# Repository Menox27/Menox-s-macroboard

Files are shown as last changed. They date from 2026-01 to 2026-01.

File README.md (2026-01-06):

# Menox-s-macroboard

This is my personal Macroboard controlled by a XIAO R2040. I redid it multiple times and this is the final version I am quite proud of. thanks to @Simon who helped me alot and thanks to whom I was able to improve my skills drasticly.
It got 9 keys, each with RGB-LEDs, a rotary encoder and a 0.91 OLED. This macroboard will be used to improve my workflow and just add more features to my setup.<br>

{3137F356-2468-4DAC-AE8C-1B506F517E0D}<br>

Schematic: <br>
This is the schematic. I split all the seperate components into diffrent wiring groups:<br>

{0275A107-F9AF-41F4-A477-3A9B39075D7F}

PCB:<br>
This is how I connected everything. It´s a little bit messy but I tried to keep it as straight forward as possible, only used 4 vias in the whole projekt and added a little bit of spongebob art.
In case you are wondering about the setup: The XIAO is mounted on the back so the OLED can be placed right above it on the frontside<br>

{1DEBE477-7064-4DE1-A112-2E3BDAD45E22}

Case:<br>
This is the case I came up with. It has a layer to mount the switches and one to hide the OLEDs parts that I dont want to be seen.<br>
{F8A3C546-25B9-4F1C-808D-FF561A60D7B6}

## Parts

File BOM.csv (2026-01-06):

Quantity | Part | Cost | Note
1x | PCB | 2€ (included) | Mainbody
1x | XIAO RP2040 | 5.50€ (included) | Microcontroller
9x | MX-Style Switches | 5.85€ (included) | Mechanical Switches
9x | any Keycaps | Filament | 3D printed
9x | Through-Hole-Diodes | 1.10€ (included) | Signal diodes
9x | SK6812 MINI-E LEDs | 0.27€ (included) | RGB Lighting
1x | EC11 Rotary Encoder | 0.65€ (included) | Input
1x | 0.91 inch OLED | 1.65€ (included) | Display
12x | M3 heatset inserts | 0.66€ (included) | Case hardware
4x | M3 Screws | 0.08€ (included) | Case hardware
1x | Macroboard-Case | Filament | 3D printed

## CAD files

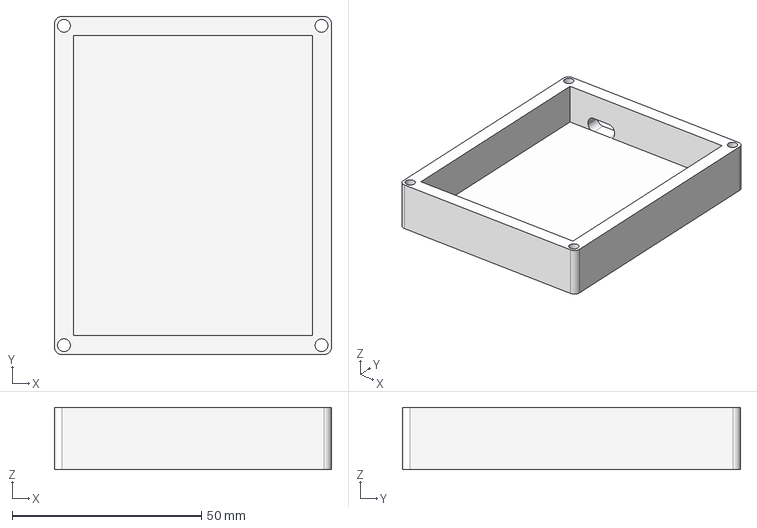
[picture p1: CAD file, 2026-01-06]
CAD/MacroboardBottomLayer.step
73.2 x 89.4 x 16.5 mm

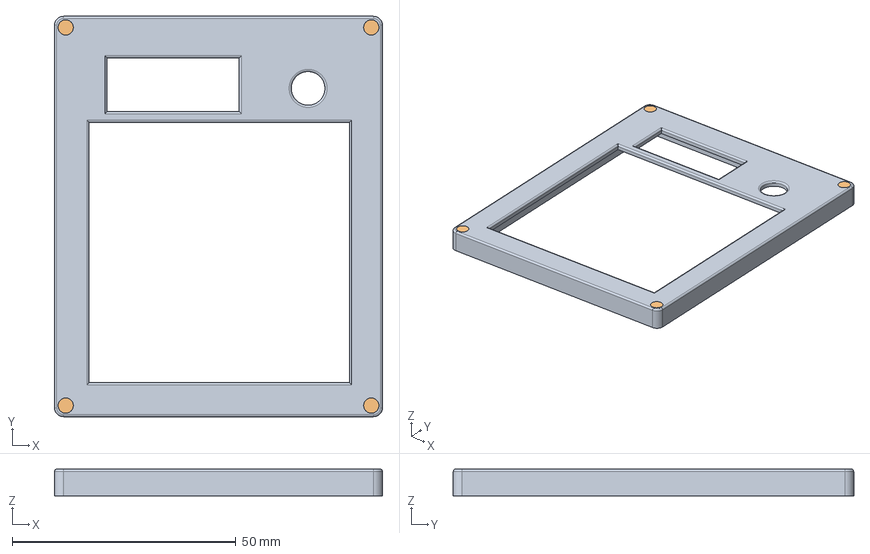
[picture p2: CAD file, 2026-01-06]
CAD/MacroboardTopLayer.step
73.2 x 89.4 x 6.00 mm

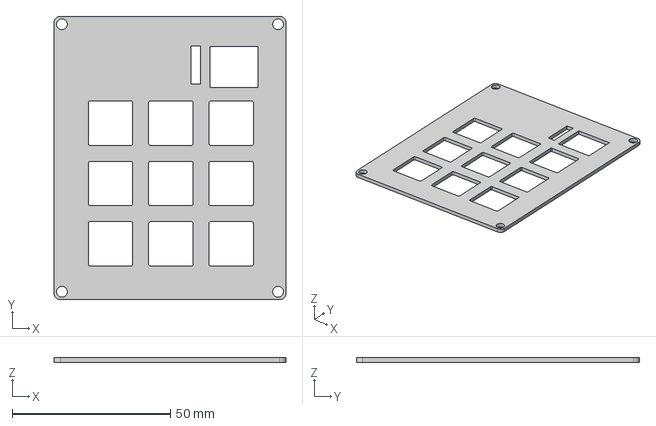
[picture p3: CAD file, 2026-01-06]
CAD/MacroboardMiddleLayer.step
73.2 x 89.4 x 1.50 mm

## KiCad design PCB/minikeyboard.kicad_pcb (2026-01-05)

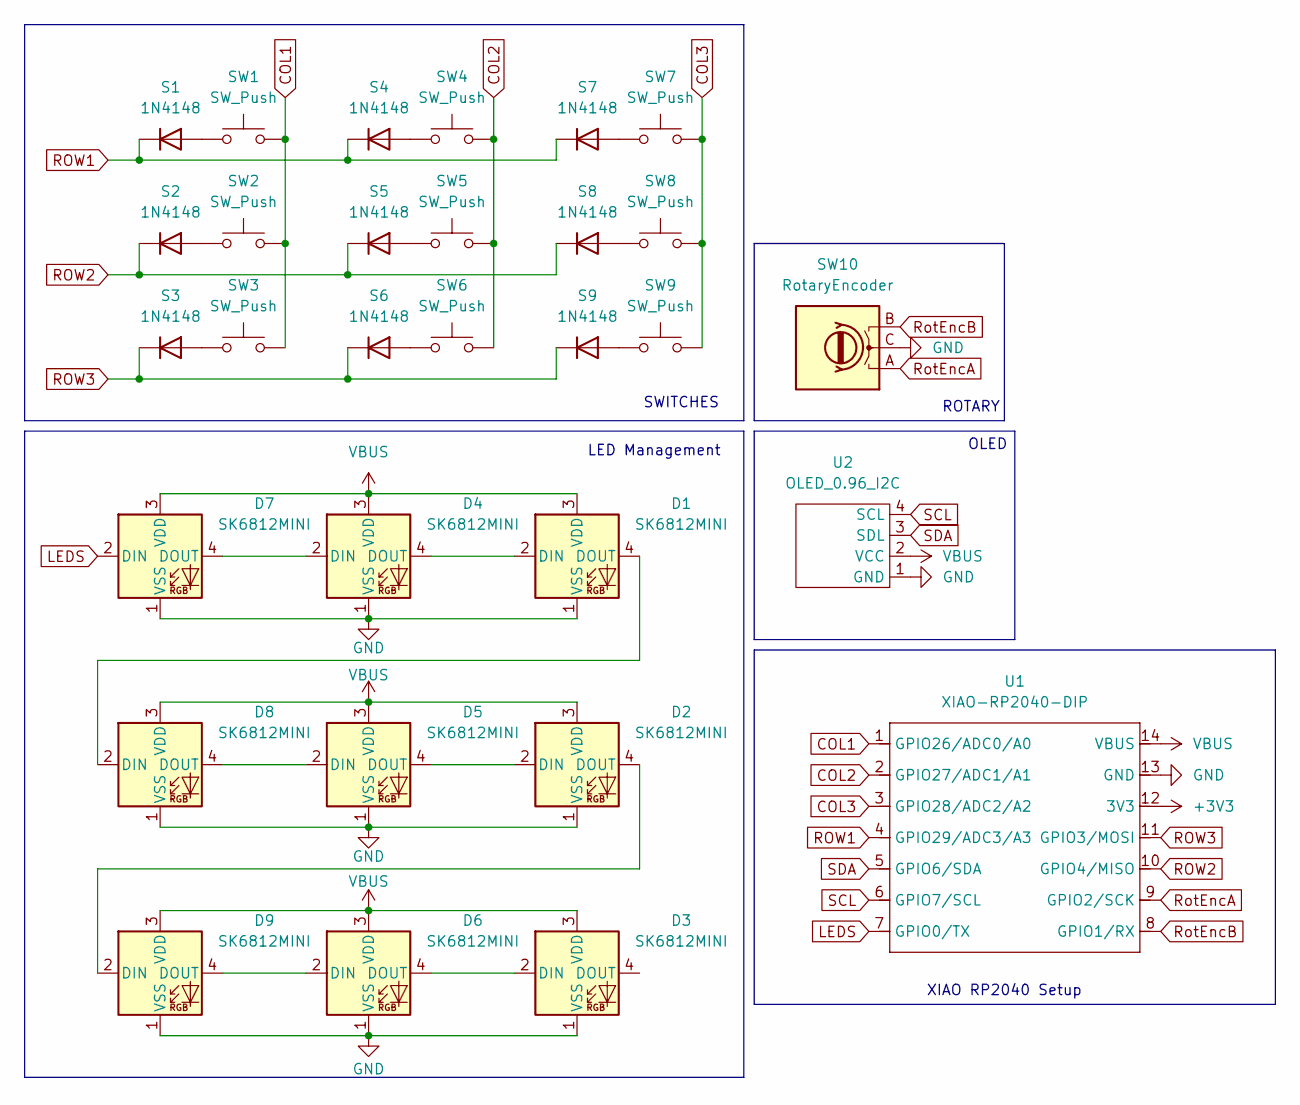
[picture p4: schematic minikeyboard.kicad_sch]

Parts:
D1, D2, D3, D4, D5, D6, D7, D8, D9: SK6812MINI; LED_SK6812MINI-E_PLCC4_3.2x2.8mm_P1.5mm
S1, S2, S3, S4, S5, S6, S7, S8, S9: 1N4148; D_DO-35_SOD27_P7.62mm_Horizontal
SW1, SW2, SW3, SW4, SW5, SW6, SW7, SW8, SW9: SW_Push; SW_Cherry_MX_1.00u_PCB
SW10: RotaryEncoder; RotaryEncoder_Alps_EC11E_Vertical_H20mm
U1: XIAO-RP2040-DIP
U2: OLED_0.96_I2C; SSD1306-0.91-OLED-4pin-128x32

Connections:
+3V3: U1.12 (3V3)
COL1: SW1.2, SW2.2, SW3.2, U1.1 (GPIO26/ADC0/A0)
COL2: SW4.2, SW5.2, SW6.2, U1.2 (GPIO27/ADC1/A1)
COL3: SW7.2, SW8.2, SW9.2, U1.3 (GPIO28/ADC2/A2)
GND: D1.1 (VSS), D2.1 (VSS), D3.1 (VSS), D4.1 (VSS), D5.1 (VSS), D6.1 (VSS), D7.1 (VSS), D8.1 (VSS), D9.1 (VSS), SW10.C, U1.13 (GND), U2.1 (GND)
LEDS: D7.2 (DIN), U1.7 (GPIO0/TX)
unnamed: D1.2 (DIN), D4.4 (DOUT)
unnamed: D1.4 (DOUT), D8.2 (DIN)
unnamed: D2.2 (DIN), D5.4 (DOUT)
unnamed: D2.4 (DOUT), D9.2 (DIN)
unnamed: D3.2 (DIN), D6.4 (DOUT)
unnamed: D4.2 (DIN), D7.4 (DOUT)
unnamed: D5.2 (DIN), D8.4 (DOUT)
unnamed: D6.2 (DIN), D9.4 (DOUT)
unnamed: S1.2 (A), SW1.1
unnamed: S2.2 (A), SW2.1
unnamed: S3.2 (A), SW3.1
unnamed: S4.2 (A), SW4.1
unnamed: S5.2 (A), SW5.1
unnamed: S6.2 (A), SW6.1
unnamed: S7.2 (A), SW7.1
unnamed: S8.2 (A), SW8.1
unnamed: S9.2 (A), SW9.1
ROW1: S1.1 (K), S4.1 (K), S7.1 (K), U1.4 (GPIO29/ADC3/A3)
ROW2: S2.1 (K), S5.1 (K), S8.1 (K), U1.10 (GPIO4/MISO)
ROW3: S3.1 (K), S6.1 (K), S9.1 (K), U1.11 (GPIO3/MOSI)
RotEncA: SW10.A, U1.9 (GPIO2/SCK)
RotEncB: SW10.B, U1.8 (GPIO1/RX)
SCL: U1.6 (GPIO7/SCL), U2.4 (SCL)
SDA: U1.5 (GPIO6/SDA), U2.3 (SDL)
VBUS: D1.3 (VDD), D2.3 (VDD), D3.3 (VDD), D4.3 (VDD), D5.3 (VDD), D6.3 (VDD), D7.3 (VDD), D8.3 (VDD), D9.3 (VDD), U1.14 (VBUS), U2.2 (VCC)

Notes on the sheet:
SWITCHES
OLED
ROTARY
XIAO RP2040 Setup
LED Management

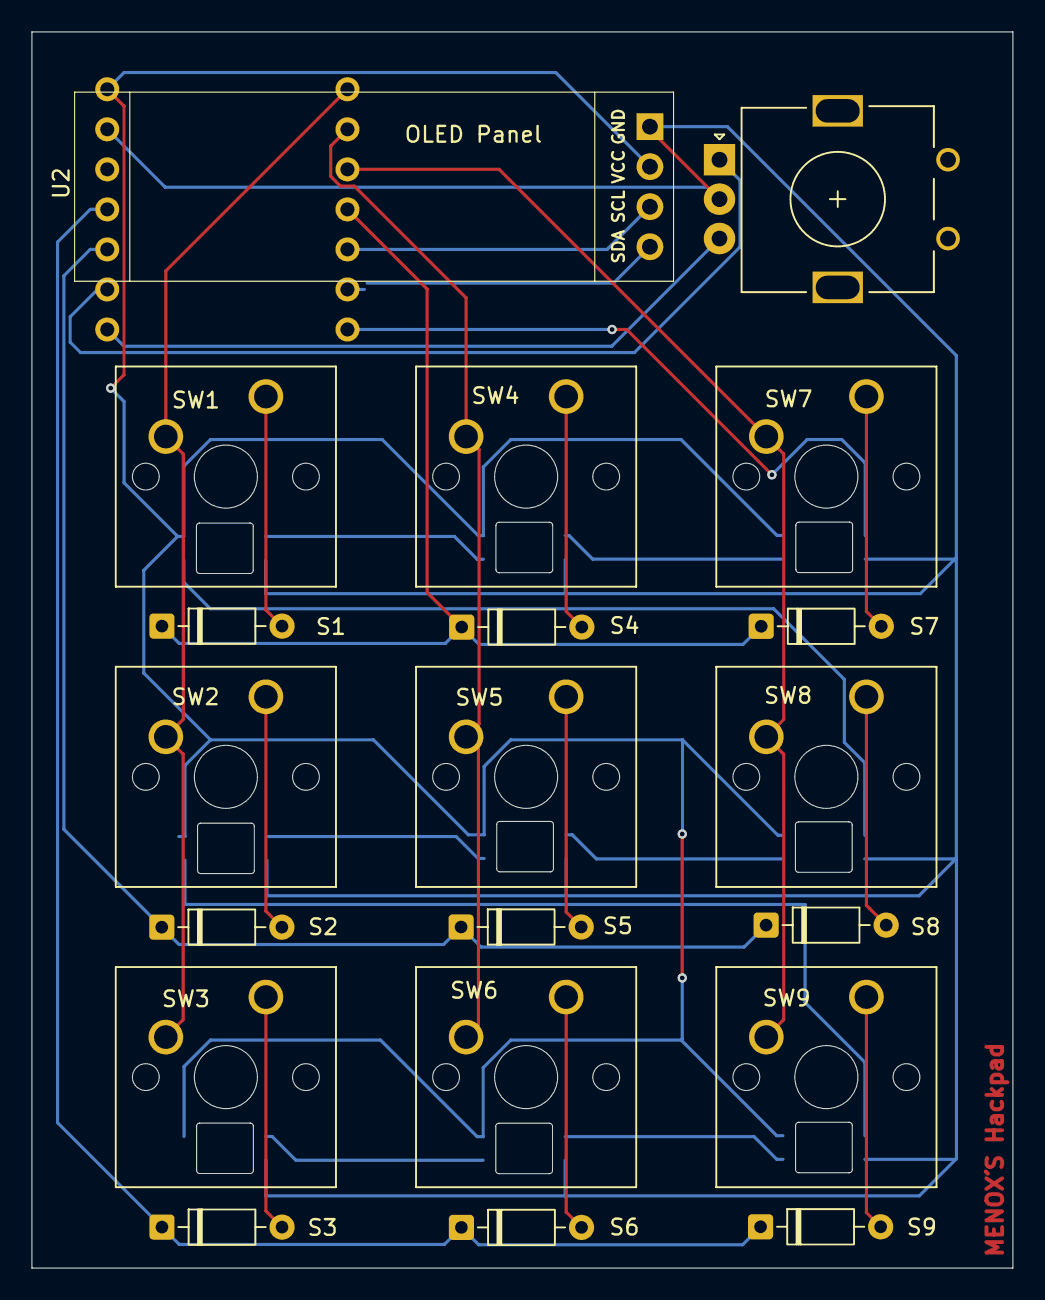
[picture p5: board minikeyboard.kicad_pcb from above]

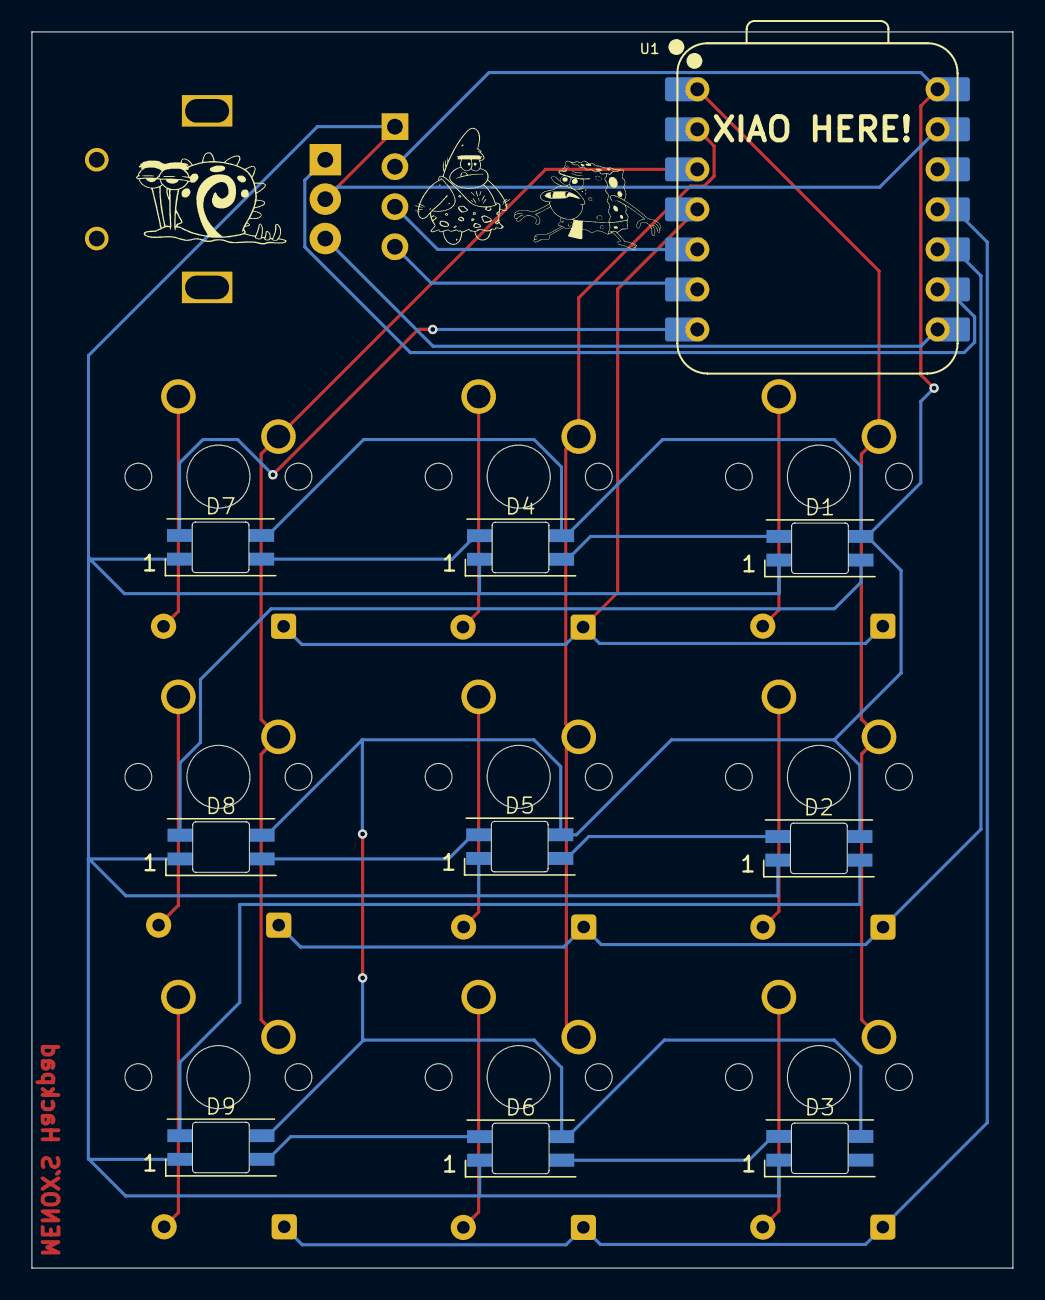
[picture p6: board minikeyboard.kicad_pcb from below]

Board: 2 copper layers, 62.2 x 78.4 mm, 30 parts (10 on the bottom side), 30 nets.

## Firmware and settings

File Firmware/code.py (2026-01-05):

import board
import analogio
import time

from kmk.kmk_keyboard import KMKKeyboard
from kmk.keys import KC
from kmk.scanners import DiodeOrientation
from kmk.modules.encoder import EncoderHandler
from kmk.modules.layers import Layers
from kmk.modules.combos import Combos, Chord
from kmk.modules.rapidkeys import RapidKeys
from kmk.extensions.display import Display, SSD1306
from kmk.extensions.rgb import RGB

keyboard = KMKKeyboard()

# 1. Hardware Setup (3x3 Matrix)
keyboard.col_pins = (board.GP26, board.GP27, board.GP28)
keyboard.row_pins = (board.GP29, board.GP3, board.GP4)
keyboard.diode_orientation = DiodeOrientation.COL2ROW

# Variablen für OLED-Helligkeit
oled_contrast = 100 

# Poti für Autoclicker-Speed (an GP2)
pot = analogio.AnalogIn(board.GP2)

# RGB Setup
rgb = RGB(pixel_pin=board.GP0, num_pixels=9, val_default=50, hue_default=140)

# 2. Module & Extensions
layers_module = Layers()
encoder_handler = EncoderHandler()
combos_module = Combos()
rapid_keys = RapidKeys()
keyboard.modules = [layers_module, encoder_handler, combos_module, rapid_keys]

# 3. Spezial-Tasten & Custom Keys
DESKTOP_RECHTS = KC.LCTL(KC.LGUI(KC.RIGHT))
DESKTOP_LINKS = KC.LCTL(KC.LGUI(KC.LEFT))
AUTOCLICK = KC.MS_BTN1.repeat(interval=50)
TASK_MANAGER = KC.LCTRL(KC.LSHIFT(KC.ESC))
ALT_TAB = KC.LALT(KC.TAB)
ENTER = KC.ENT

# 4. OLED Display Logik
i2c_bus = board.I2C()
display_driver = SSD1306(i2c=i2c_bus, device_address=0x3C)

class MyDisplay(Display):
    def on_runtime_report(self, keyboard):
        global oled_contrast
        self.driver.fill(0)
        layer = keyboard.active_layers[0]
        
        # OLED Helligkeit anwenden
        self.driver.contrast(oled_contrast)
        
        if layer == 0:
            interval = AUTOCLICK.interval
            self.driver.text('MACRO MODE', 0, 0, 1)
            self.driver.text(f'Speed: {interval}ms', 0, 20, 1)
            rgb.set_hsv(140, 100, rgb.val) # Eisblau
        else:
            self.driver.text('SETTINGS', 0, 0, 1)
            self.driver.text(f'RGB-Bright: {int(rgb.val/255*100)}%', 0, 15, 1)
            self.driver.text(f'OLED-Contrast: {oled_contrast}', 0, 30, 1)
            rgb.set_hsv(0, 255, rgb.val) # Rot
        self.driver.show()

display_extension = MyDisplay(display_driver)
keyboard.extensions = [rgb, display_extension]

# 5. Custom Code für OLED Steuerung
def oled_br_up(keyboard, *args):
    global oled_contrast
    oled_contrast = min(oled_contrast + 25, 255)

def oled_br_down(keyboard, *args):
    global oled_contrast
    oled_contrast = max(oled_contrast - 25, 0)

KC_OLED_UP = KC.NO.clone()
KC_OLED_UP.on_press.append(oled_br_up)
KC_OLED_DOWN = KC.NO.clone()
KC_OLED_DOWN.on_press.append(oled_br_down)

# 6. Combos & Encoder
combos_module.combos = [Chord((ALT_TAB, ENTER), KC.TG(1))]

encoder_handler.pins = ((board.GP2, board.GP1, None, False),)
encoder_handler.map = [
    ((KC.VOLU, KC.VOLD),),        # Layer 0: System Volume
    ((KC.RGB_VAI, KC.RGB_VAD),),  # Layer 1: RGB Helligkeit
]

# 7. Die Keymap
keyboard.keymap = [
    [   # LAYER 0 (Macro Layer)
        KC.MUTE,       DESKTOP_LINKS,  DESKTOP_RECHTS, 
        KC.LCTRL(KC.C), KC.LCTRL(KC.V), TASK_MANAGER,   
        ALT_TAB,       AUTOCLICK,      ENTER           
    ],
    [   # LAYER 1 (Settings Layer)
        KC.TRNS,      KC.TRNS,        KC.TRNS,
        KC.TRNS,      KC.TRNS,        KC_OLED_UP,   # Taste 6: OLED Heller
        KC.TRNS,      KC.TRNS,        KC_OLED_DOWN  # Taste 9: OLED Dunkler
    ]
]

def update_poti_speed(keyboard):
    AUTOCLICK.interval = int(10 + (pot.value / 65535) * 500)

keyboard.before_matrix_scan.append(update_poti_speed)

if __name__ == '__main__':
    keyboard.go()

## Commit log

2025-12-22 adding the files
    [casfertig.step, minikeyboard.kicad_pcb, minikeyboard.kicad_sch]
2025-12-25 new case with PCB inside
    [casfertig.3mf, casfertig.step]
2025-12-25 Enhance README with project details and images
    Added detailed descriptions, images, and BOM for the macroboard.
2026-01-05 Complete overhaul of the layout, parts and case
    for better use and higher quality
    [casfertig.3mf, minikeyboard.kicad_pcb, minikeyboard.kicad_sch]
2026-01-05 Error-fixing
    Had to reupload the PCB due to wrong placement of "XIAO here" (B.Cu instead B.Silkscreen)
    [minikeyboard.kicad_pcb]
2026-01-05 Revise README with detailed macroboard description
    Updated the README to provide a more detailed description of the macroboard, including its features and components. Added images and improved clarity of the schematic, PCB, and case sections.
2026-01-05 final update with all correct files
    Finished the Macroboard after a few long nights 😄
    Still very fun project! would recommend trying it urself
    [MenoxsMacroboardCase.step]
2026-01-05 Revise BOM format to include costs in a table
    Updated the Bill of Materials (BOM) format to a table with costs.
2026-01-05 Remove BOM section from README.md
    Removed BOM section from the README. Will add a BOM.csv
2026-01-05 Add BOM.csv with bill of materials
    [BOM.csv]
2026-01-06 adding the single files
    [MacroboardBottomLayer.step, MacroboardMiddleLayer.step, MacroboardTopLayer.step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]
